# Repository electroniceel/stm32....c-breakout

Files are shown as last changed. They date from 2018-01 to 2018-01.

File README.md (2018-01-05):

STM32....C (LQFP48 and UFQFPN48) Breakout Module
================================================

A breakout module for STM32 microcontrollers in LQFP48 and UFQFPN48 footprint.

Basic Features
--------------

* Focus on small footprint and direct access to most pins.
* 40 pins broken out, organized as two single row headers in 2.54mm pitch 
* Footprints for USB-B (THT) or Micro-USB (SMT) Header
* Provides a 8 pin Micro-MaTch header for easy access to SWD and UART.
* Pushbutton for Reset (press <1 second) and starting the bootloader (press >3 seconds).
* Onboard LDO regulator (standard SOT-23-5) can be used for VDD and VDDA, just VDD or bypassed completely.
* USB VBUS (5V) is available on a pin and can be routed to the onboard LDO
* Dedicated USB disconnect function with proper pullup & disable (conforming to USB spec, not some dirty trickery)
* Use of a crystal (SMT 3.2x2.5mm) is optional.
* Options can be configured using solder bridges.
* Power LED and User LED (on PC13, PB13 or disconnected).
* Size: 25x51mm or 20x10 pins in the standard 2.54mm raster

Available pins
--------------

These pins are available on the 2.54mm headers:

* PA0 - PA12, PA15
* PB0 - PB15
* PC13 - PC15
* 5V (USB Vbus or input to the LDO regulator)
* Vdd
* Vdda
* Vbat
* NRST
* GND (2 times), also used on Vssa

These pins are also available on the Micro-MaTch:

* SWCLK, SWDIO, SWO
* NRST
* GND
* Vdd
* UART RX, UART TX (which ones can be selected via solder bridges)

These pins are not individually broken out:

* Vssa (directly connected to GND)
* PD0, PD1 (only connected to the onboard crystal pads)
* Boot0 (only connected to the reset / bootloader button)

Comparison to the popular "Blue Pill" boards
---------------------------------------------

* Allows to select the STM32 model you want, even the F4 models
* Allows to select the optimal power configuration via solder bridges
* Gives access to the bootloader via button press
* USB disconnect function allows using USB based bootloaders without hassle
* Better engineered
    * Proper ESD protection for USB
    * Ferrite beads in the power traces
    * Pads for proper decoupling caps
* Conveniant development with SWD, SWO, NRST, UART on one Micro-MaTch connector
* Possible to use THT USB-B sockets which are mechanically more stable

Downside is that it is larger, Blue Pill uses 20x7 pins raster.

Some of the supported microcontrollers
------------------------------------

* STM32F070CB
* STM32F072C8, STM32F072CB
* STM32F102C8, STM32F102CB
* STM32F103C8, STM32F103CB
* STM32F301C8
* STM32F302C8, STM32F302CB, STM32F302CC
* STM32F303C8, STM32F303CB, STM32F303CC
* STM32F334C6, STM32F334C8
* STM32F401CB, STM32F401CC, STM32F401CD, STM32F401CE
* STM32F411CC, STM32F411CE
* STM32F412CE, STM32F412CG
* STM32F413CG, STM32F413CH, STM32F423CH
* STM32L151C6-A, STM32L151C8-A, STM32L151CB-A
* STM32L152C6-A, STM32L152C8-A, STM32L152CB-A

These are just the ones that I checked for compatibility. Since ST regards pinout compatibility higly,
nearly all STM32 controllers in LQFP48 and UFQFPN48 packages should work on this board.

Schematics & Layout
-------------------

Schematics & Layout were done in KiCAD.

[Schematics as PDF](https://github.com/electroniceel/stm32....c-breakout/raw/master/schematics.pdf)

Picture
-------

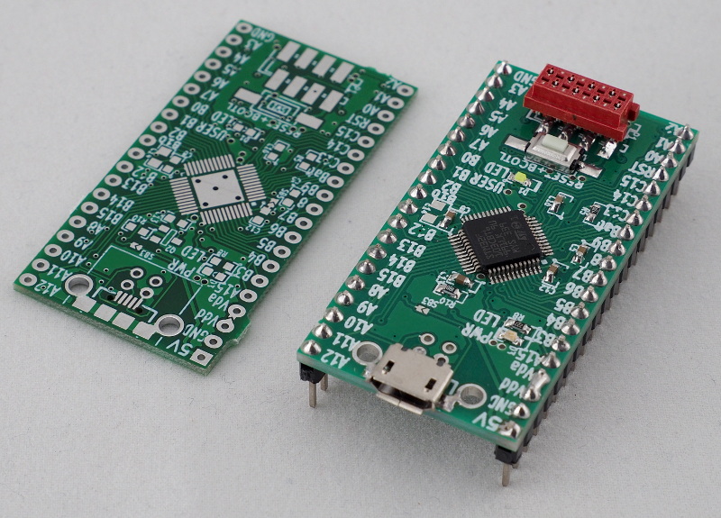
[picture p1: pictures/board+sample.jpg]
Module and raw PCB


License
-------


This work is licensed under a [Creative Commons Attribution 4.0 International License](https://creativecommons.org/licenses/by/4.0/).

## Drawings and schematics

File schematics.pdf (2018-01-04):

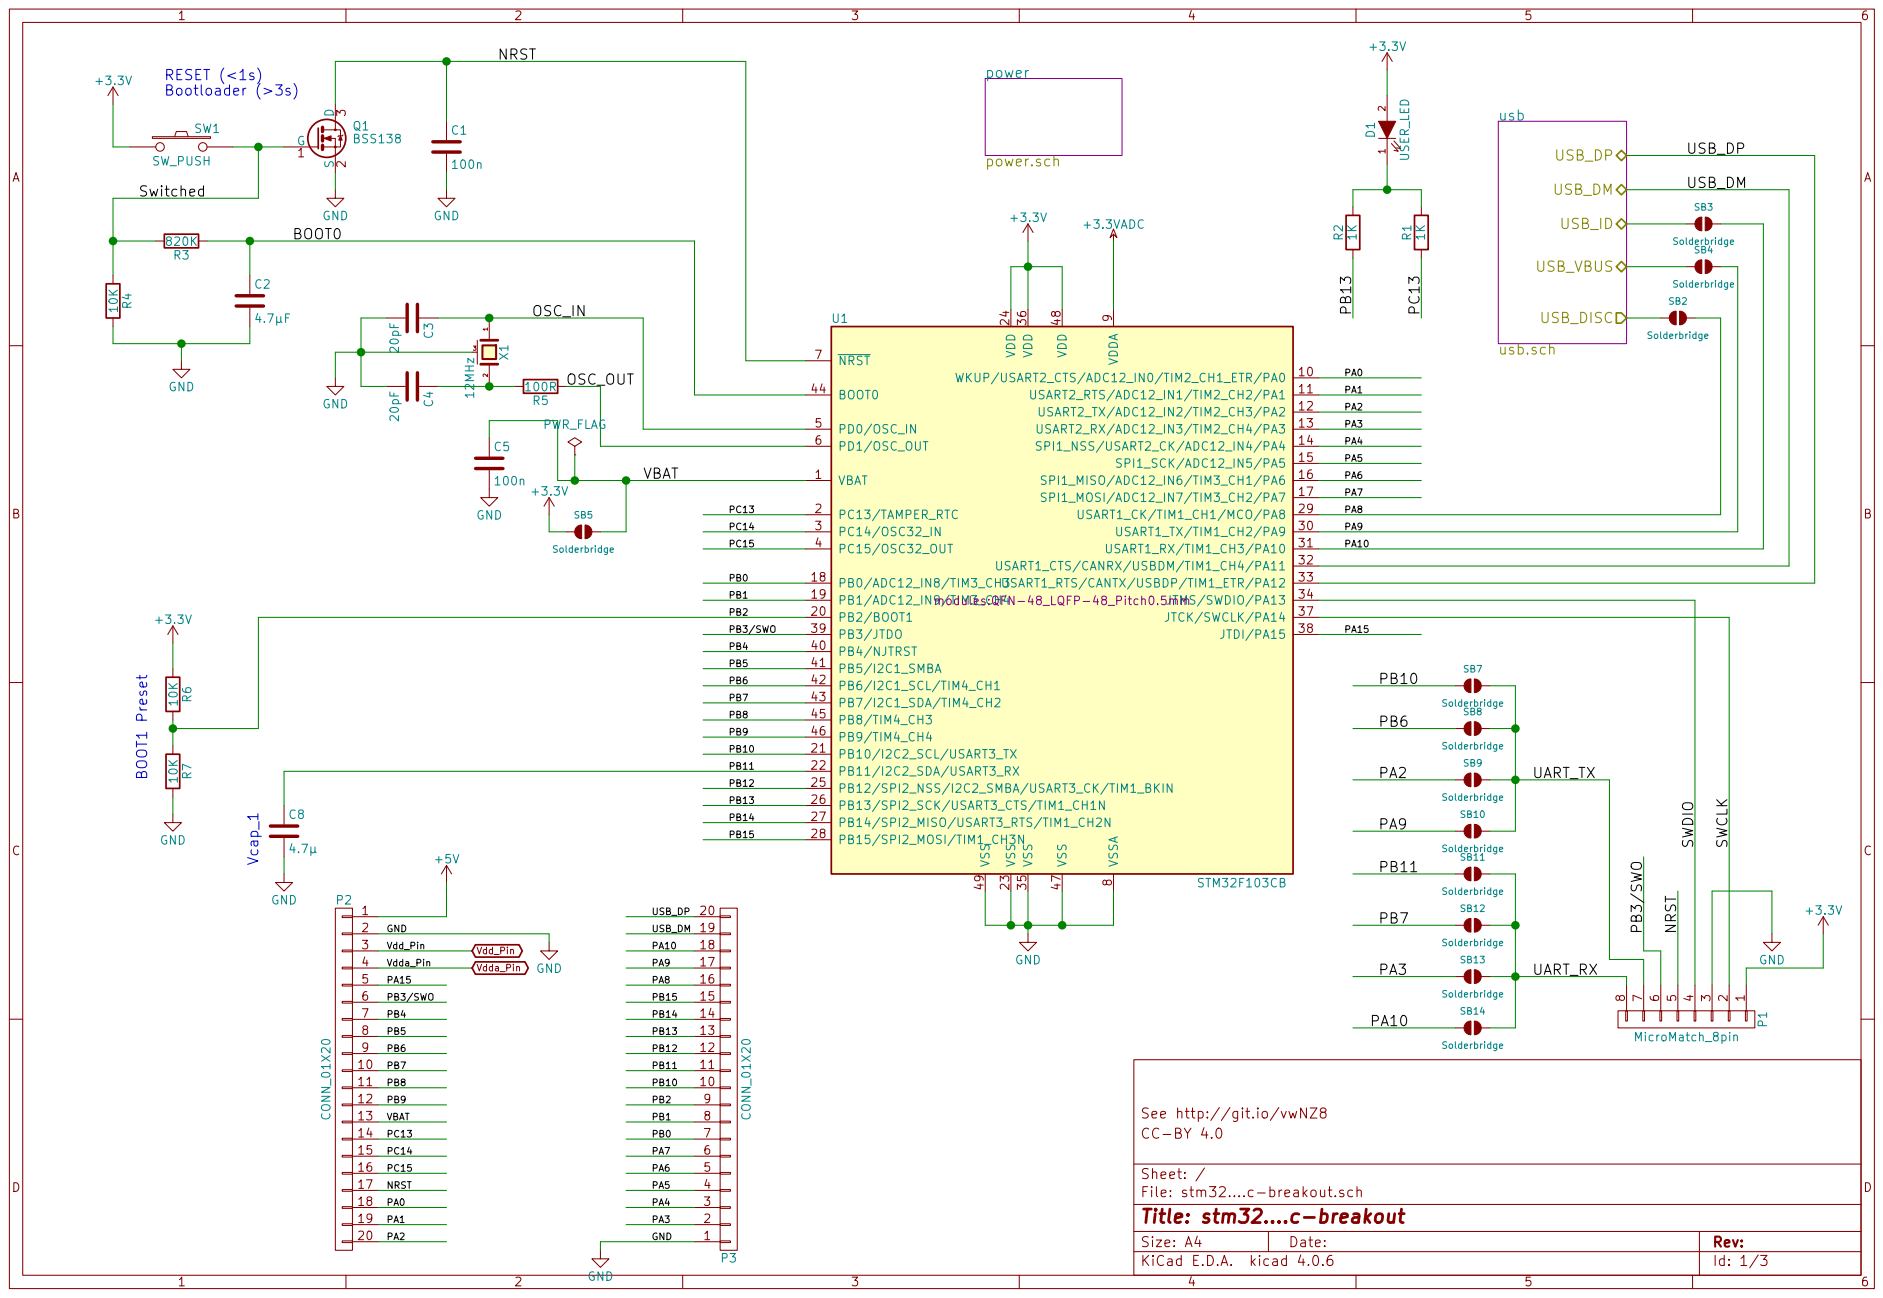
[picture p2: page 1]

9 WKUP/USART2_CTS/ADC12_IN0/TIM2_CH1_ETR/PA0 10 PB2/BOOT1 20 USART1_TX/TIM1_CH2/PA9 30 PB4/NJTRST 40 USART2_RTS/ADC12_IN1/TIM2_CH2/PA1 11 PB10/I2C2_SCL/USART3_TX 21 USART1_RX/TIM1_CH3/PA10 31 PB5/I2C1_SMBA 41 USART2_TX/ADC12_IN2/TIM2_CH3/PA2 12 PB11/I2C2_SDA/USART3_RX 22 USART1_CTS/CANRX/USBDM/TIM1_CH4/PA11 32 PB6/I2C1_SCL/TIM4_CH1 42 USART2_RX/ADC12_IN3/TIM2_CH4/PA3 13 VSS 23 USART1_RTS/CANTX/USBDP/TIM1_ETR/PA12 33 PB7/I2C1_SDA/TIM4_CH2 43 SPI1_NSS/USART2_CK/ADC12_IN4/PA4 14 VDD 24

SB13 Solderbridge SB14 Solderbridge SB12 Solderbridge SB10 Solderbridge SB9 Solderbridge SB8 Solderbridge PA10 PA9 PA2 PA3

Id: 1/3 Title: stm32....c-breakout File: stm32....c-breakout.sch Sheet: / CC-BY 4.0 See http://git.io/vwNZ8

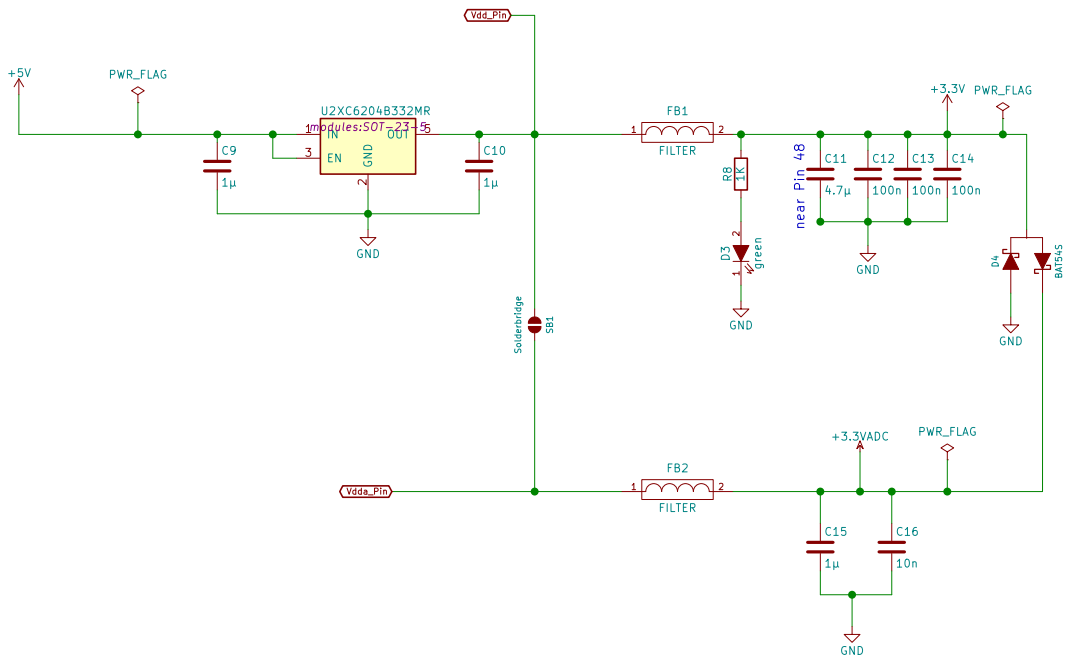
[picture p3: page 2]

2 EN 3 OUT 5 U2 XC6204B332MR modules:SOT-23-5 C9

Sheet: /power/ CC-BY 4.0 See http://git.io/vwNZ8

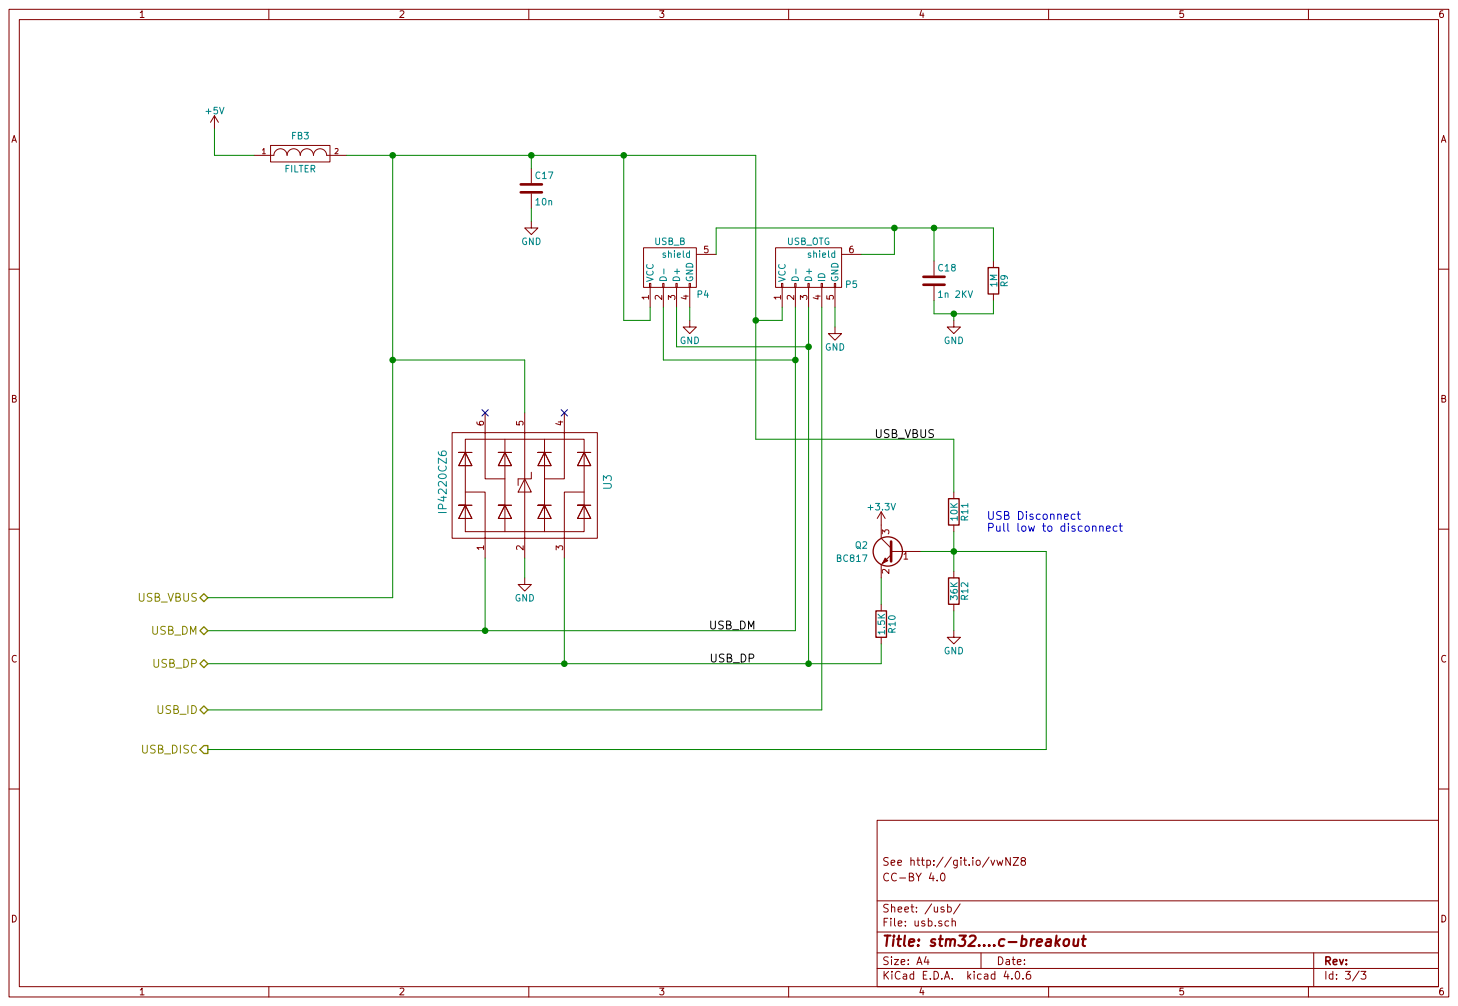
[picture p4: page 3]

3 GND
Id: 3/3 Title: stm32....c-breakout File: usb.sch Sheet: /usb/ CC-BY 4.0 See http://git.io/vwNZ8 VCC

2 3 Q2 BC817 10K R11 36K R12 GND USB Disconnect Pull low to disconnect USB_VBUS

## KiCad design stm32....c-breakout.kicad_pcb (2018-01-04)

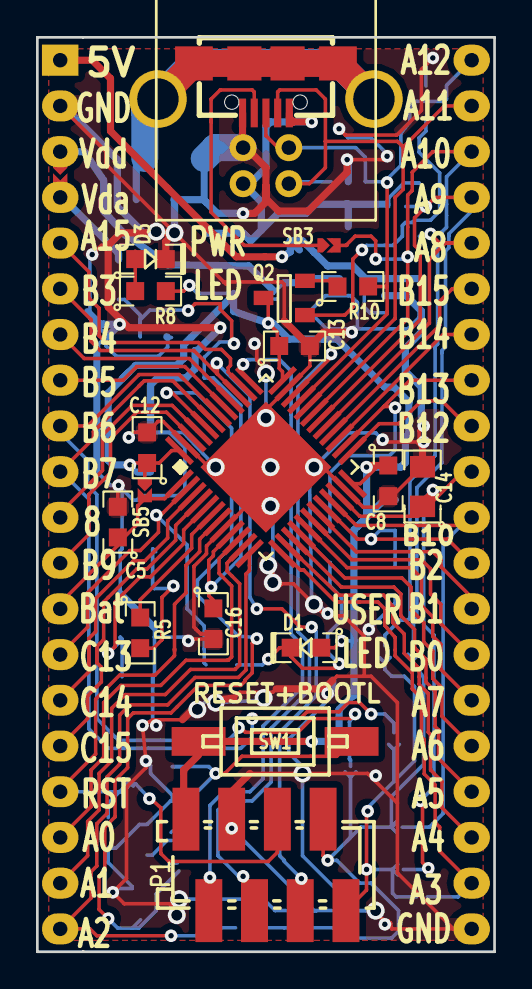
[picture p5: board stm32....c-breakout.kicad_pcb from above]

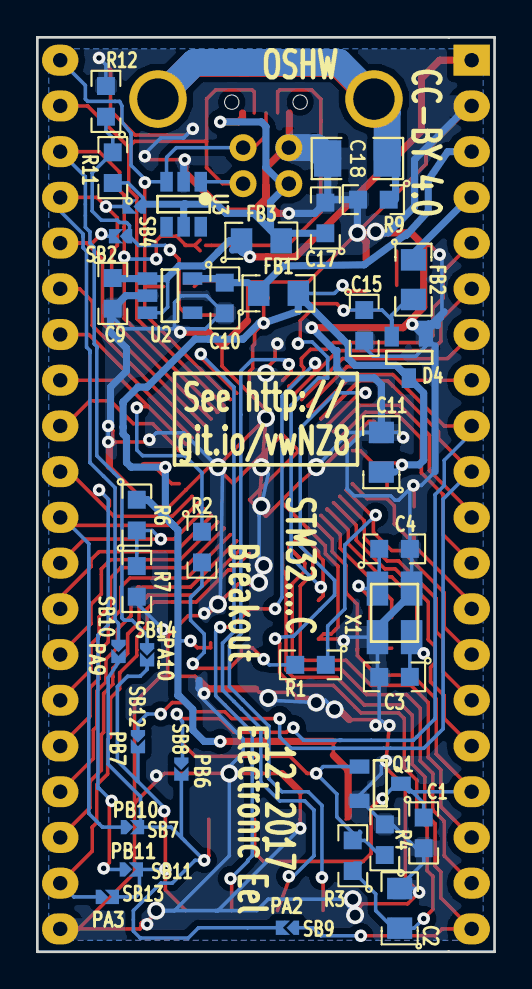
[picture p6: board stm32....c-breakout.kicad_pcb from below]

Board: 2 copper layers, 25.4 x 50.8 mm, 59 parts (37 on the bottom side), 57 nets.

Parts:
C1, C5, C12, C13, C14: 100n; SMD0603-wide-C
C2: 4.7µF; SMD0805-wide-C
C3, C4: 20pF; SMD0603-wide-C
C8, C11: 4.7µ; SMD0805-wide-C
C9, C10, C15: 1µ; SMD0603-wide-C
C16, C17: 10n; SMD0603-wide-C
C18: 1n 2KV; SMD1206-wide
D1: USER_LED; SMD0603-wide-diode
D3: green; SMD0603-wide-diode
D4: BAT54S; SOT-23
FB1, FB2, FB3: FILTER; SMD0805-wide
P1: MicroMatch_8pin; Conn-Micromatch-SMD-8
P2, P3: CONN_01X20; Pin_Header_Straight_1x20
P4: USB_B; USB_B-THT
P5: USB_OTG; Micro-USB-AB-receptacle-SMT
Q1: BSS138; SOT-23
Q2: BC817; SOT-23
R1, R2, R8: 1K; SMD0603-wide-R
R3: 820K; SMD0603-wide-R
R4, R6, R7, R11: 10K; SMD0603-wide-R
R5: 100R; SMD0603-wide-R
R9: 1M; SMD0603-wide-R
R10: 1.5K; SMD0603-wide-R
R12: 36K; SMD0603-wide-R
SB1: Solderbridge; Solderbridge-wide
SB2, SB3, SB4, SB5, SB7, SB8, SB9, SB10, SB11, SB12, SB13, SB14: Solderbridge
SW1: SW_PUSH; Push-Button-SMD-6.0x3.5mm
U1: STM32F103CB; QFN-48_LQFP-48_Pitch0.5mm
U2: XC6204B332MR; SOT-23-5
U3: IP4220CZ6; SOT-23-6
X1: 12MHz; smd-xtal-3225

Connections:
+3.3VADC: C15.1, C16.1, D4.2, FB2.2, U1.9
+3V3: C11.1, C12.1, C13.1, C14.1, D1.2, D4.3, FB1.2, P1.1, Q2.3, R6.1, R8.2, SB5.1, SW1.1, U1.24, U1.36, U1.48
+5V: C9.1, FB3.1, P2.1, U2.1, U2.3
/BOOT0: C2.1, R3.1, U1.44
/NRST: C1.1, P1.5, P2.17, Q1.3, U1.7
/OSC_IN: C3.1, U1.5, X1.1
/OSC_OUT: R5.1, U1.6
/PA0: P2.18, U1.10
/PA1: P2.19, U1.11
/PA2: P2.20, SB9.1, U1.12
/PA3: P3.2, SB13.1, U1.13
/PA4: P3.3, U1.14
/PA5: P3.4, U1.15
/PA6: P3.5, U1.16
/PA7: P3.6, U1.17
/PA8: P3.16, SB2.2, U1.29
/PA9: P3.17, SB4.2, SB10.1, U1.30
/PA10: P3.18, SB3.2, SB14.1, U1.31
/PA15: P2.5, U1.38
/PB0: P3.7, U1.18
/PB1: P3.8, U1.19
/PB2: P3.9, R6.2, R7.1, U1.20
/PB3/SWO: P1.6, P2.6, U1.39
/PB4: P2.7, U1.40
/PB5: P2.8, U1.41
/PB6: P2.9, SB8.1, U1.42
/PB7: P2.10, SB12.1, U1.43
/PB8: P2.11, U1.45
/PB9: P2.12, U1.46
/PB10: P3.10, SB7.1, U1.21
/PB11: C8.1, P3.11, SB11.1, U1.22
/PB12: P3.12, U1.25
/PB13: P3.13, R2.1, U1.26
/PB14: P3.14, U1.27
/PB15: P3.15, U1.28
/PC13: P2.14, R1.1, U1.2
/PC14: P2.15, U1.3
/PC15: P2.16, U1.4
/SWCLK: P1.2, U1.37
/SWDIO: P1.4, U1.34
/Switched: Q1.1, R3.2, R4.1, SW1.2
/UART_RX: P1.8, SB11.2, SB12.2, SB13.2, SB14.2
/UART_TX: P1.7, SB7.2, SB8.2, SB9.2, SB10.2
/USB_DM: P3.19, P4.2, P5.2, U1.32, U3.1
/USB_DP: P3.20, P4.3, P5.3, R10.2, U1.33, U3.3
/VBAT: C5.1, P2.13, SB5.2, U1.1
/usb/USB_DISC: Q2.1, R11.2, R12.1, SB2.1
/usb/USB_ID: P5.4, SB3.1
/usb/USB_VBUS: C17.1, FB3.2, P4.1, P5.1, R11.1, SB4.1, U3.5
GND: C1.2, C2.2, C3.2, C4.2, C5.2, C8.2, C9.2, C10.2, C11.2, C12.2, C13.2, C14.2, C15.2, C16.2, C17.2, C18.2, D3.1, D4.1, P1.3, P2.2, P3.1, P4.4, P5.5, Q1.2, R4.2, R7.2, R9.2, R12.2, U1.8, U1.23, U1.35, U1.47, U1.49, U2.2, U3.2, X1.3
unnamed: C4.1, R5.2, X1.2
unnamed: C18.1, P4.5, P5.6, R9.1
unnamed: D1.1, R1.2, R2.2
unnamed: D3.2, R8.1
unnamed: Q2.2, R10.1
Vdd_Pin: C10.1, FB1.1, P2.3, SB1.1, U2.5
Vdda_Pin: FB2.1, P2.4, SB1.2

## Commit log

2018-01-04 add actual kicad files
    [power.sch, stm32....c-breakout.kicad_pcb, stm32....c-breakout.sch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]
2018-01-04 add pictures and schematics.pdf
